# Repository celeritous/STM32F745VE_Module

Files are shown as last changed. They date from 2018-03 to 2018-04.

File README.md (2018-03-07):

# STM32F745VE_Module
This repository is for an STM32F745VE Cortex M7 32bit ARM processor module. The design supports most of the STM32F7xx processors in the QFP100 package. 

The design is in KiCad and is released under the CERN OHL Ver 1.2 It is on a 50mm x 50mm 4 layer PCB with two 38 Pin dual row 100mil headers for user power and IO. There is no on-board voltage regulation so the user must supply regulated 3.3V power to the board. 

Features include a USB FS and HS ports that can function as host or client as well as and optional uSD card slot and optional Ethernet RMII PHY chip and connector.  

Along with the hardware design, the repository also contains a sample STM32CubeMX pin assignemt project file and a sample Atollic TrueStudio project file generated by the STM32CubeMX project file.

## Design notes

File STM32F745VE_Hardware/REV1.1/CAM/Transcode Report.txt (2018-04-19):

   ---- Transcoding 'C:\Users\alitton\Dropbox\Github\STM32F745VE_Module\STM32F745VE_Hardware\REV1.1\CAM\STM32F745VE_REV1.1-B.Cu.gbl' ----   Wed Apr 11 17:01:41 2018

D11   --> D100
D12   --> D101
D13   --> D102
D14   --> D103
D15   --> D104
D16   --> D105
D17   --> D106
D18   --> D107
-----------------------------------------------------------------

   ---- Transcoding 'C:\Users\alitton\Dropbox\Github\STM32F745VE_Module\STM32F745VE_Hardware\REV1.1\CAM\STM32F745VE_REV1.1-B.Mask.gbs' ----   Wed Apr 11 17:01:41 2018

D11   --> D108
D12   --> D109
D13   --> D110
D14   --> D111
D15   --> D112
D16   --> D113
D17   --> D114
D18   --> D115
D19   --> D116
D20   --> D117
D21   --> D118
D22   --> D119
D23   --> D120
D24   --> D121
-----------------------------------------------------------------

   ---- Transcoding 'C:\Users\alitton\Dropbox\Github\STM32F745VE_Module\STM32F745VE_Hardware\REV1.1\CAM\STM32F745VE_REV1.1-B.SilkS.gbo' ----   Wed Apr 11 17:01:41 2018

D11   --> D122
D12   --> D123
D13   --> D124
D14   --> D125
D15   --> D126
D16   --> D127
-----------------------------------------------------------------

   ---- Transcoding 'C:\Users\alitton\Dropbox\Github\STM32F745VE_Module\STM32F745VE_Hardware\REV1.1\CAM\STM32F745VE_REV1.1-Edge.Cuts.gm1' ----   Wed Apr 11 17:01:41 2018

D11   --> D128
-----------------------------------------------------------------

   ---- Transcoding 'C:\Users\alitton\Dropbox\Github\STM32F745VE_Module\STM32F745VE_Hardware\REV1.1\CAM\STM32F745VE_REV1.1-F.Cu.gtl' ----   Wed Apr 11 17:01:41 2018

D11   --> D129
D12   --> D130
D13   --> D131
D14   --> D132
D15   --> D133
D16   --> D134
D17   --> D135
D18   --> D136
D19   --> D137
D20   --> D138
D21   --> D139
D22   --> D140
D23   --> D141
D24   --> D142
D25   --> D143
-----------------------------------------------------------------

   ---- Transcoding 'C:\Users\alitton\Dropbox\Github\STM32F745VE_Module\STM32F745VE_Hardware\REV1.1\CAM\STM32F745VE_REV1.1-F.Mask.gts' ----   Wed Apr 11 17:01:41 2018

D11   --> D144
D12   --> D145
D13   --> D146
D14   --> D147
D15   --> D148
D16   --> D149
D17   --> D150
D18   --> D151
D19   --> D152
D20   --> D153
D21   --> D154
D22   --> D155
D23   --> D156
D24   --> D157
D25   --> D158
-----------------------------------------------------------------

   ---- Transcoding 'C:\Users\alitton\Dropbox\Github\STM32F745VE_Module\STM32F745VE_Hardware\REV1.1\CAM\STM32F745VE_REV1.1-F.SilkS.gto' ----   Wed Apr 11 17:01:41 2018

D11   --> D159
D12   --> D160
D13   --> D161
D14   --> D162
D15   --> D163
D16   --> D164
-----------------------------------------------------------------

   ---- Transcoding 'C:\Users\alitton\Dropbox\Github\STM32F745VE_Module\STM32F745VE_Hardware\REV1.1\CAM\STM32F745VE_REV1.1-B.Cu.gbl' ----   Wed Apr 11 17:21:39 2018

D11   --> D100
D12   --> D101
D13   --> D102
D14   --> D103
D15   --> D104
D16   --> D105
D17   --> D106
D18   --> D107
-----------------------------------------------------------------

   ---- Transcoding 'C:\Users\alitton\Dropbox\Github\STM32F745VE_Module\STM32F745VE_Hardware\REV1.1\CAM\STM32F745VE_REV1.1-B.Mask.gbs' ----   Wed Apr 11 17:21:39 2018

D11   --> D108
D12   --> D109
D13   --> D110
D14   --> D111
D15   --> D112
D16   --> D113
D17   --> D114
D18   --> D115
D19   --> D116
D20   --> D117
D21   --> D118
D22   --> D119
D23   --> D120
D24   --> D121
-----------------------------------------------------------------

   ---- Transcoding 'C:\Users\alitton\Dropbox\Github\STM32F745VE_Module\STM32F745VE_Hardware\REV1.1\CAM\STM32F745VE_REV1.1-B.SilkS.gbo' ----   Wed Apr 11 17:21:39 2018

D11   --> D122
D12   --> D123
D13   --> D124
D14   --> D125
D15   --> D126
D16   --> D127
-----------------------------------------------------------------

   ---- Transcoding 'C:\Users\alitton\Dropbox\Github\STM32F745VE_Module\STM32F745VE_Hardware\REV1.1\CAM\STM32F745VE_REV1.1-Edge.Cuts.gm1' ----   Wed Apr 11 17:21:39 2018

D11   --> D128
-----------------------------------------------------------------

   ---- Transcoding 'C:\Users\alitton\Dropbox\Github\STM32F745VE_Module\STM32F745VE_Hardware\REV1.1\CAM\STM32F745VE_REV1.1-F.Cu.gtl' ----   Wed Apr 11 17:21:39 2018

D11   --> D129
D12   --> D130
D13   --> D131
D14   --> D132
D15   --> D133
D16   --> D134
D17   --> D135
D18   --> D136
D19   --> D137
D20   --> D138
D21   --> D139
D22   --> D140
D23   --> D141
D24   --> D142
D25   --> D143
-----------------------------------------------------------------

   ---- Transcoding 'C:\Users\alitton\Dropbox\Github\STM32F745VE_Module\STM32F745VE_Hardware\REV1.1\CAM\STM32F745VE_REV1.1-F.Mask.gts' ----   Wed Apr 11 17:21:39 2018

D11   --> D144
D12   --> D145
D13   --> D146
D14   --> D147
D15   --> D148
D16   --> D149
D17   --> D150
D18   --> D151
D19   --> D152
D20   --> D153
D21   --> D154
D22   --> D155
D23   --> D156
D24   --> D157
D25   --> D158
-----------------------------------------------------------------

   ---- Transcoding 'C:\Users\alitton\Dropbox\Github\STM32F745VE_Module\STM32F745VE_Hardware\REV1.1\CAM\STM32F745VE_REV1.1-F.SilkS.gto' ----   Wed Apr 11 17:21:39 2018

D11   --> D159
D12   --> D160
D13   --> D161
D14   --> D162
D15   --> D163
D16   --> D164
-----------------------------------------------------------------

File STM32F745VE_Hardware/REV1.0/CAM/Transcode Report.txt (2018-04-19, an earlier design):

   ---- Transcoding 'C:\Users\alitton\Dropbox\Github\STM32F745VE_Module\STM32F745VE_Hardware\REV1.0\CAM\STM32F745VE_Module-B.Cu.gbl' ----   Tue Apr 10 13:23:34 2018

D11   --> D100
D12   --> D101
D13   --> D102
D14   --> D103
D15   --> D104
D16   --> D105
D17   --> D106
D18   --> D107
-----------------------------------------------------------------

   ---- Transcoding 'C:\Users\alitton\Dropbox\Github\STM32F745VE_Module\STM32F745VE_Hardware\REV1.0\CAM\STM32F745VE_Module-F.Cu.gtl' ----   Tue Apr 10 13:23:34 2018

D11   --> D108
D12   --> D109
D13   --> D110
D14   --> D111
D15   --> D112
D16   --> D113
D17   --> D114
D18   --> D115
D19   --> D116
D20   --> D117
D21   --> D118
D22   --> D119
D23   --> D120
D24   --> D121
D25   --> D122
D26   --> D123
D27   --> D124
-----------------------------------------------------------------

   ---- Transcoding 'C:\Users\alitton\Dropbox\Github\STM32F745VE_Module\STM32F745VE_Hardware\REV1.0\CAM\STM32F745VE_Module-B.Mask.gbs' ----   Tue Apr 10 14:13:37 2018

D11   --> D125
D12   --> D126
D13   --> D127
D14   --> D128
D15   --> D129
D16   --> D130
D17   --> D131
D18   --> D132
D19   --> D133
D20   --> D134
D21   --> D135
D22   --> D136
D23   --> D137
-----------------------------------------------------------------

   ---- Transcoding 'C:\Users\alitton\Dropbox\Github\STM32F745VE_Module\STM32F745VE_Hardware\REV1.0\CAM\STM32F745VE_Module-B.SilkS.gbo' ----   Tue Apr 10 14:13:37 2018

D11   --> D138
D12   --> D139
D13   --> D140
D14   --> D141
D15   --> D142
D16   --> D143
-----------------------------------------------------------------

   ---- Transcoding 'C:\Users\alitton\Dropbox\Github\STM32F745VE_Module\STM32F745VE_Hardware\REV1.0\CAM\STM32F745VE_Module-Edge.Cuts.gm1' ----   Tue Apr 10 14:13:37 2018

D11   --> D144
-----------------------------------------------------------------

   ---- Transcoding 'C:\Users\alitton\Dropbox\Github\STM32F745VE_Module\STM32F745VE_Hardware\REV1.0\CAM\STM32F745VE_Module-F.Mask.gts' ----   Tue Apr 10 14:13:37 2018

D11   --> D145
D12   --> D146
D13   --> D147
D14   --> D148
D15   --> D149
D16   --> D150
D17   --> D151
D18   --> D152
D19   --> D153
D20   --> D154
D21   --> D155
D22   --> D156
D23   --> D157
D24   --> D158
D25   --> D159
-----------------------------------------------------------------

   ---- Transcoding 'C:\Users\alitton\Dropbox\Github\STM32F745VE_Module\STM32F745VE_Hardware\REV1.0\CAM\STM32F745VE_Module-F.SilkS.gto' ----   Tue Apr 10 14:13:37 2018

D11   --> D160
D12   --> D161
D13   --> D162
D14   --> D163
D15   --> D164
D16   --> D165
-----------------------------------------------------------------

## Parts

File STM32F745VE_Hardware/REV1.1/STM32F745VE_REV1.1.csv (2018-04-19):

Id | Designator | Package | Quantity | Designation
1 | C1,C2,C3,C4 | P0603 | 4 | 12pF
2 | D1,D2 | SOT23-6 | 2 | USBLC6-2
3 | J1 | CONNECTOR_ETHERNET_SI60062 | 1 | CONNECTOR_RJ45_SI-60062
4 | J3,J4 | CONN_USB_UX60-MB | 2 | USB_MINI_B_SMD
5 | U1 | QFP_100_14X14_0.5 | 1 | STM32F745VE
6 | U2 | QFN24_4X4mm_0.5mm_PWR | 1 | KSZ8081RNA
7 | U3 | SOT23-6 | 1 | 24AA02E64OT
8 | X1 | XTAL_1.8X4.9mm | 1 | ABS10-32.768kHz
9 | X2 | XTAL_3.2X2.5 | 1 | ABM8G-12.00MHz
10 | P2,P3 | Header_2x17_Shrouded_100mil | 2 | Header_2x17
11 | C5,C6,C8,C9,C11,C13,C14,C15,C16,C17 | P0603 | 10 | 0.10uF
12 | C7,C23,C24 | P0603 | 3 | 2.2uF
13 | C10,C12,C18,C19,C20,C21,C22 | P0603 | 7 | 10.0uF
14 | D3 | SOD123 | 1 | SMP3V3
15 | F1 | P1812 | 1 | FUSE_PTC_.75A_33V
16 | L1,L2 | P0603 | 2 | FERRITE_BEAD
17 | P4,P5 | Header_2x1_Shrouded_100mil | 2 | Header_2x1
18 | R1 | P0603 | 1 | 6.49kΩ
19 | R2,R3 | P0603 | 2 | 220.0Ω
20 | U4 | SOT23-6 | 1 | MCP1501-30
21 | P1 | Connector_1x4_100mil_TH | 1 | CONN_1x4
22 | J2 | CONN_SDMICRO_3M | 1 | SOCKET_MICRO_SD_SMT_3M
23 | C25 | P0603 | 1 | 0.010uF
24 | R4,R5,R6,R7,R8 | P0603 | 5 | 4.70kΩ
25 | SW1 | SWITCH_6MM_PB | 1 | PUSHBUTTON_SPST_6MM_SMD
26 | D4 | MINI_SMA | 1 | D_Small
29 | R9,R10 | P0603 | 2 | ZERO_Ω
30 | R11,R12 | P0603 | 2 | 1.50kΩ

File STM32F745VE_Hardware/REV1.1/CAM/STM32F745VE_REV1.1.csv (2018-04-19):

Id | Designator | Package | Quantity | Designation | Supplier and ref
1 | U1 | QFP_100_14X14_0.5 | 1 | STM32F745VE
2 | J2 | CONN_SDMICRO_3M | 1 | SOCKET_MICRO_SD_SMT_3M
3 | C1,C2,C3,C4 | P0603 | 4 | 12pF
4 | D1,D2 | SOT23-6 | 2 | USBLC6-2
5 | J1 | CONNECTOR_ETHERNET_SI60062 | 1 | CONNECTOR_RJ45_SI-60062
6 | J3,J4 | CONN_USB_UX60-MB | 2 | USB_MINI_B_SMD
7 | U2 | QFN24_4X4mm_0.5mm_PWR | 1 | KSZ8081RNA
8 | U3 | SOT23-6 | 1 | 24AA02E64OT
9 | X1 | XTAL_1.8X4.9mm | 1 | ABS10-32.768kHz
10 | X2 | XTAL_3.2X2.5 | 1 | ABM8G-12.00MHz
11 | P2,P3 | Header_2x17_Shrouded_100mil | 2 | Header_2x17
12 | C5,C6,C8,C9,C11,C13,C14,C15,C16,C17 | P0603 | 10 | 0.10uF
13 | C7,C23,C24 | P0603 | 3 | 2.2uF
14 | C10,C12,C18,C19,C20,C21,C22 | P0603 | 7 | 10.0uF
15 | D3 | SOD123 | 1 | SMP3V3
16 | F1 | P1812 | 1 | FUSE_PTC_.75A_33V
17 | L1,L2 | P0603 | 2 | FERRITE_BEAD
18 | P4,P5 | Header_2x1_Shrouded_100mil | 2 | Header_2x1
19 | R1 | P0603 | 1 | 6.49kΩ
20 | R2,R3 | P0603 | 2 | 220.0Ω
21 | U4 | SOT23-6 | 1 | MCP1501-30
22 | P1 | Connector_1x4_100mil_TH | 1 | CONN_1x4
23 | C25 | P0603 | 1 | 0.010uF
24 | R4,R5,R6,R7,R8,R14 | P0603 | 6 | 4.70kΩ
25 | SW1 | SWITCH_6MM_PB | 1 | PUSHBUTTON_SPST_6MM_SMD
26 | D4 | MINI_SMA | 1 | D_Small
27 | REF03,REF02 | FIDUCIAL_TOP | 2 | FIDUCIAL_TOP
28 | REF04,REF01 | FIDUCIAL_BOTTOM | 2 | FIDUCIAL_BOTTOM
29 | R9,R10,R13 | P0603 | 3 | ZERO_Ω
30 | R11,R12 | P0603 | 2 | 1.50kΩ

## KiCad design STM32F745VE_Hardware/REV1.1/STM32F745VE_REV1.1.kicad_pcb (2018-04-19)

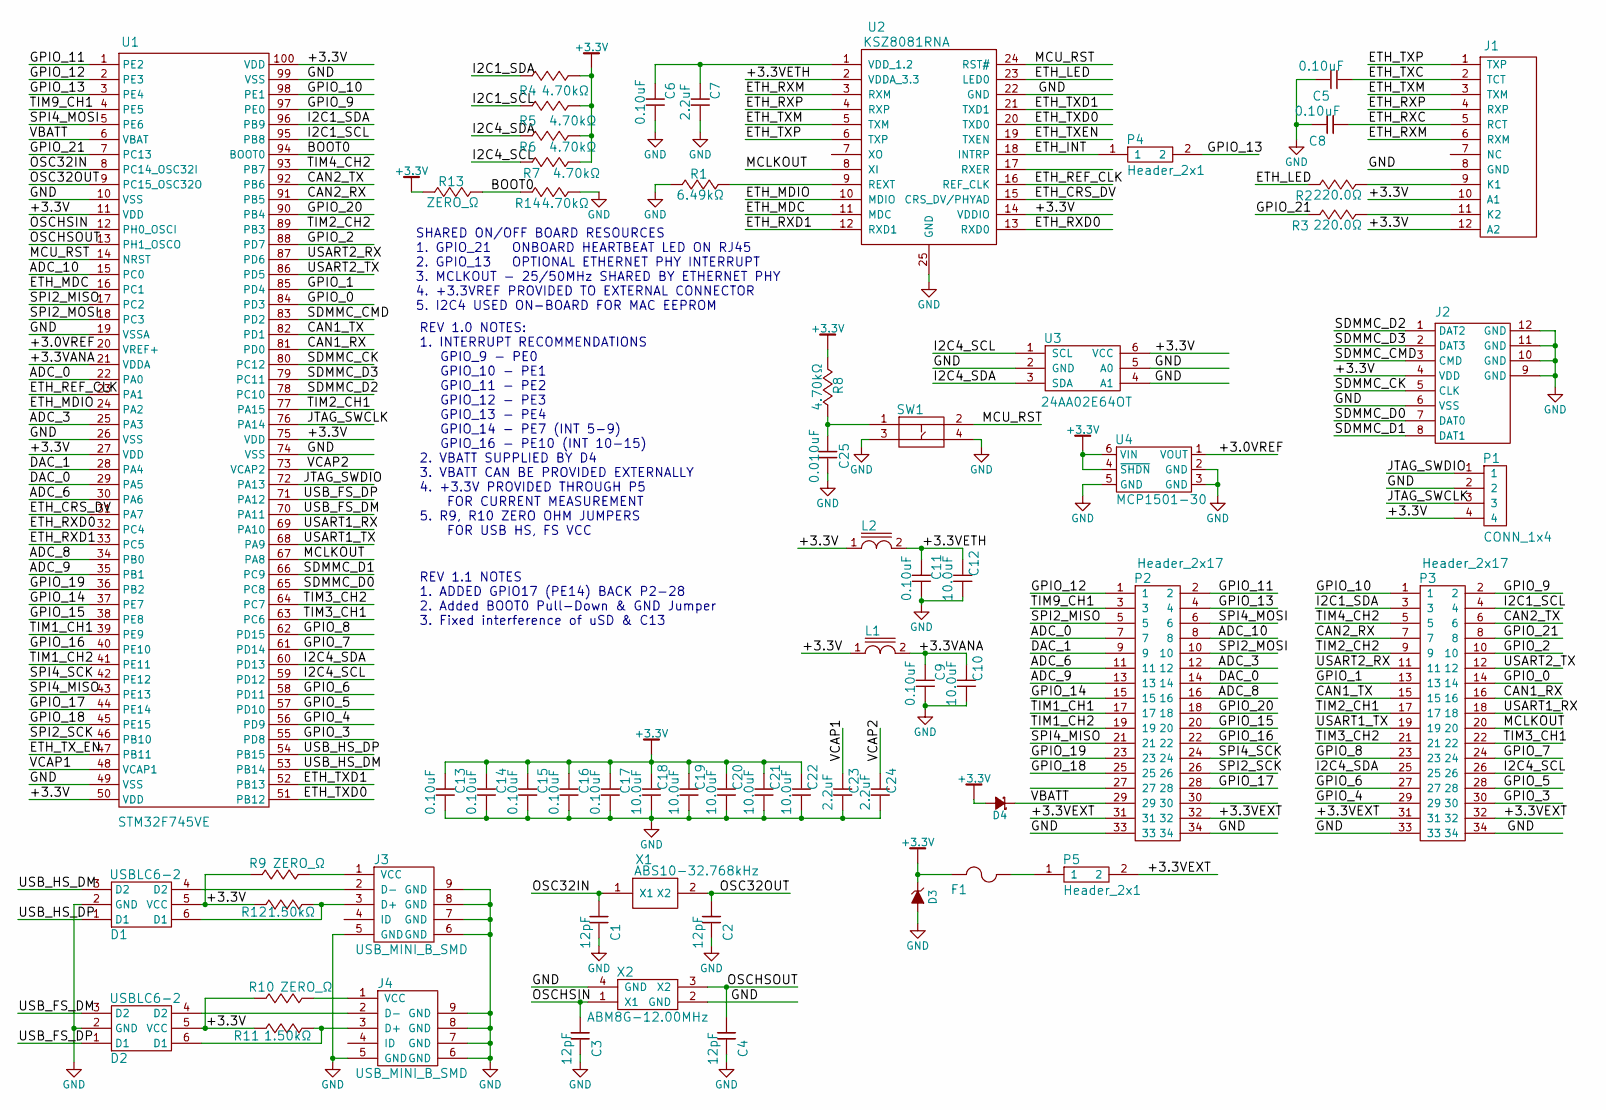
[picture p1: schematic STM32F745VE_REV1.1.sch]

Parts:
C1, C2, C3, C4: 12pF; P0603
C5, C6, C8, C9, C11, C13, C14, C15, C16, C17: 0.10uF; P0603
C7, C23, C24: 2.2uF; P0603
C10, C12, C18, C19, C20, C21, C22: 10.0uF; P0603
C25: 0.010uF; P0603
D1, D2: USBLC6-2; SOT23-6
D3: SMP3V3; DO220AA
D4: D_Small; MINI_SMA
F1: FUSE_PTC_.75A_33V; P1812
J1: CONNECTOR_RJ45_SI-60062; CONNECTOR_ETHERNET_SI60062
J2: SOCKET_MICRO_SD_SMT_3M; CONN_SDMICRO_3M
J3, J4: USB_MINI_B_SMD; CONN_USB_UX60-MB
L1, L2: FERRITE_BEAD; P0603
P1: CONN_1x4; Connector_1x4_100mil_TH
P2, P3: Header_2x17; Header_2x17_Shrouded_100mil
P4, P5: Header_2x1; Header_2x1_Shrouded_100mil
R1: 6.49kΩ; P0603
R2, R3: 220.0Ω; P0603
R4, R5, R6, R7, R8, R14: 4.70kΩ; P0603
R9, R10, R13: ZERO_Ω; P0603
R11, R12: 1.50kΩ; P0603
SW1: PUSHBUTTON_SPST_6MM_SMD; SWITCH_6MM_PB
U1: STM32F745VE; QFP_100_14X14_0.5
U2: KSZ8081RNA; QFN24_4X4mm_0.5mm_PWR
U3: 24AA02E64OT; SOT23-6
U4: MCP1501-30; SOT23-6
X1: ABS10-32.768kHz; XTAL_1.8X4.9mm
X2: ABM8G-12.00MHz; XTAL_3.2X2.5

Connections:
+3.3V: C13.1, C14.1, C15.1, C16.1, C17.1, C18.1, C19.1, C20.1, C21.1, C22.1, D1.5 (VCC), D2.5 (VCC), D3.K, D4.A, F1.1, J1.10 (A1), J1.12 (A2), J2.4 (VDD), L1.1, L2.1, P1.4, R4.2, R5.2, R6.2, R7.2, R8.1, R9.1, R10.1, R11.1, R12.2, R13.1, U1.11 (VDD), U1.27 (VDD), U1.50 (VDD), U1.75 (VDD), U1.100 (VDD), U2.14 (VDDIO), U3.6 (VCC), U4.4 (~SHDN), U4.6 (VIN)
/+3.0VREF: U1.20 (VREF+), U4.1 (VOUT)
/+3.3VANA: C9.1, C10.1, L1.2, U1.21 (VDDA)
/+3.3VETH: C11.1, C12.1, L2.2, U2.2 (VDDA_3.3)
/+3.3VEXT: P2.31, P2.32, P3.31, P3.32, P5.2
/ADC_0: P2.7, U1.22 (PA0)
/ADC_3: P2.12, U1.25 (PA3)
/ADC_6: P2.11, U1.30 (PA6)
/ADC_8: P2.16, U1.34 (PB0)
/ADC_9: P2.13, U1.35 (PB1)
/ADC_10: P2.8, U1.15 (PC0)
/BOOT0: R13.2, R14.1, U1.94 (BOOT0)
/CAN1_RX: P3.16, U1.81 (PD0)
/CAN1_TX: P3.15, U1.82 (PD1)
/CAN2_RX: P3.7, U1.91 (PB5)
/CAN2_TX: P3.6, U1.92 (PB6)
/DAC_0: P2.14, U1.29 (PA5)
/DAC_1: P2.9, U1.28 (PA4)
/ETH_CRS_DV: U1.31 (PA7), U2.15 (CRS_DV/PHYAD)
/ETH_INT: P4.1, U2.18 (INTRP)
/ETH_LED: R2.1, U2.23 (LED0)
/ETH_MDC: U1.16 (PC1), U2.11 (MDC)
/ETH_MDIO: U1.24 (PA2), U2.10 (MDIO)
/ETH_REF_CLK: U1.23 (PA1), U2.16 (REF_CLK)
/ETH_RXC: C8.1, J1.5 (RCT)
/ETH_RXD0: U1.32 (PC4), U2.13 (RXD0)
/ETH_RXD1: U1.33 (PC5), U2.12 (RXD1)
/ETH_RXM: J1.6 (RXM), U2.3 (RXM)
/ETH_RXP: J1.4 (RXP), U2.4 (RXP)
/ETH_TXC: C5.1, J1.2 (TCT)
/ETH_TXD0: U1.51 (PB12), U2.20 (TXD0)
/ETH_TXD1: U1.52 (PB13), U2.21 (TXD1)
/ETH_TXEN: U2.19 (TXEN)
/ETH_TXM: J1.3 (TXM), U2.5 (TXM)
/ETH_TXP: J1.1 (TXP), U2.6 (TXP)
/ETH_TX_EN: U1.47 (PB11)
/GPIO_0: P3.14, U1.84 (PD3)
/GPIO_1: P3.13, U1.85 (PD4)
/GPIO_2: P3.10, U1.88 (PD7)
/GPIO_3: P3.30, U1.55 (PD8)
/GPIO_4: P3.29, U1.56 (PD9)
/GPIO_5: P3.28, U1.57 (PD10)
/GPIO_6: P3.27, U1.58 (PD11)
/GPIO_7: P3.24, U1.61 (PD14)
/GPIO_8: P3.23, U1.62 (PD15)
/GPIO_9: P3.2, U1.97 (PE0)
/GPIO_10: P3.1, U1.98 (PE1)
/GPIO_11: P2.2, U1.1 (PE2)
/GPIO_12: P2.1, U1.2 (PE3)
/GPIO_13: P2.4, P4.2, U1.3 (PE4)
/GPIO_14: P2.15, U1.37 (PE7)
/GPIO_15: P2.20, U1.38 (PE8)
/GPIO_16: P2.22, U1.40 (PE10)
/GPIO_17: P2.28, U1.44 (PE14)
/GPIO_18: P2.25, U1.45 (PE15)
/GPIO_19: P2.23, U1.36 (PB2)
/GPIO_20: P2.18, U1.90 (PB4)
/GPIO_21: P3.8, R3.1, U1.7 (PC13)
/I2C1_SCL: P3.4, R5.1, U1.95 (PB8)
/I2C1_SDA: P3.3, R4.1, U1.96 (PB9)
/I2C4_SCL: P3.26, R7.1, U1.59 (PD12), U3.1 (SCL)
/I2C4_SDA: P3.25, R6.1, U1.60 (PD13), U3.3 (SDA)
/JTAG_SWCLK: P1.3, U1.76 (PA14)
/JTAG_SWDIO: P1.1, U1.72 (PA13)
/MCLKOUT: P3.20, U1.67 (PA8), U2.8 (XI)
/MCU_RST: SW1.2, U1.14 (NRST), U2.24 (RST#)
/OSC32IN: C1.1, U1.8 (PC14_OSC32I), X1.1 (X1)
/OSC32OUT: C2.1, U1.9 (PC15_OSC32O), X1.2 (X2)
/OSCHSIN: C3.1, U1.12 (PH0_OSCI), X2.1 (X1)
/OSCHSOUT: C4.1, U1.13 (PH1_OSCO), X2.3 (X2)
/SDMMC_CK: J2.5 (CLK), U1.80 (PC12)
/SDMMC_CMD: J2.3 (CMD), U1.83 (PD2)
/SDMMC_D0: J2.7 (DAT0), U1.65 (PC8)
/SDMMC_D1: J2.8 (DAT1), U1.66 (PC9)
/SDMMC_D2: J2.1 (DAT2), U1.78 (PC10)
/SDMMC_D3: J2.2 (DAT3), U1.79 (PC11)
/SPI2_MISO: P2.5, U1.17 (PC2)
/SPI2_MOSI: P2.10, U1.18 (PC3)
/SPI2_SCK: P2.26, U1.46 (PB10)
/SPI4_MISO: P2.21, U1.43 (PE13)
/SPI4_MOSI: P2.6, U1.5 (PE6)
/SPI4_SCK: P2.24, U1.42 (PE12)
/TIM1_CH1: P2.17, U1.39 (PE9)
/TIM1_CH2: P2.19, U1.41 (PE11)
/TIM2_CH1: P3.17, U1.77 (PA15)
/TIM2_CH2: P3.9, U1.89 (PB3)
/TIM3_CH1: P3.22, U1.63 (PC6)
/TIM3_CH2: P3.21, U1.64 (PC7)
/TIM4_CH2: P3.5, U1.93 (PB7)
/TIM9_CH1: P2.3, U1.4 (PE5)
/USART1_RX: P3.18, U1.69 (PA10)
/USART1_TX: P3.19, U1.68 (PA9)
/USART2_RX: P3.11, U1.87 (PD6)
/USART2_TX: P3.12, U1.86 (PD5)
/USB_FS_DM: D2.3 (D2), U1.70 (PA11)
/USB_FS_DP: D2.1 (D1), U1.71 (PA12)
/USB_HS_DM: D1.3 (D2), U1.53 (PB14)
/USB_HS_DP: D1.1 (D1), U1.54 (PB15)
/VBATT: D4.K, P2.29, U1.6 (VBAT)
/VCAP1: C23.1, U1.48 (VCAP1)
/VCAP2: C24.1, U1.73 (VCAP2)
GND: C1.2, C2.2, C3.2, C4.2, C5.2, C6.2, C7.2, C8.2, C9.2, C10.2, C11.2, C12.2, C13.2, C14.2, C15.2, C16.2, C17.2, C18.2, C19.2, C20.2, C21.2, C22.2, C23.2, C24.2, C25.2, D1.2 (GND), D2.2 (GND), D3.A, J1.8 (GND), J2.6 (VSS), J2.9 (GND), J2.10 (GND), J2.11 (GND), J2.12 (GND), J3.5 (GND), J3.6 (GND), J3.7 (GND), J3.8 (GND), J3.9 (GND), J4.5 (GND), J4.6 (GND), J4.7 (GND), J4.8 (GND), J4.9 (GND), P1.2, P2.33, P2.34, P3.33, P3.34, R1.1, R14.2, SW1.3, SW1.4, U1.10 (VSS), U1.19 (VSSA), U1.26 (VSS), U1.49 (VSS), U1.74 (VSS), U1.99 (VSS), U2.22 (GND), U2.25 (GND), U3.2 (GND), U3.4 (A1), U3.5 (A0), U4.2 (GND), U4.3 (GND), U4.5 (GND), X2.2 (GND), X2.4 (GND)
unnamed: C6.1, C7.1, U2.1 (VDD_1.2)
unnamed: C25.1, R8.2, SW1.1
unnamed: D1.4 (D2), J3.2 (D-)
unnamed: D1.6 (D1), J3.3 (D+), R12.1
unnamed: D2.4 (D2), J4.2 (D-)
unnamed: D2.6 (D1), J4.3 (D+), R11.2
unnamed: F1.2, P5.1
unnamed: J1.9 (K1), R2.2
unnamed: J1.11 (K2), R3.2
unnamed: J3.1 (VCC), R9.2
unnamed: J4.1 (VCC), R10.2
unnamed: R1.2, U2.9 (REXT)

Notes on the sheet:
SHARED ON/OFF BOARD RESOURCES 1. GPIO_21 ONBOARD HEARTBEAT LED ON RJ45 2. GPIO_13 OPTIONAL ETHERNET PHY INTERRUPT 3. MCLKOUT - 25/50MHz SHARED BY ETHERNET PHY 4. +3.3VREF PROVIDED TO EXTERNAL CONNECTOR 5. I2C4 USED ON-BOARD FOR MAC EEPROM
REV 1.0 NOTES: 1. INTERRUPT RECOMMENDATIONS GPIO_9 - PE0 GPIO_10 - PE1 GPIO_11 - PE2 GPIO_12 - PE3 GPIO_13 - PE4 GPIO_14 - PE7 (INT 5-9) GPIO_16 - PE10 (INT 10-15) 2. VBATT SUPPLIED BY D4 3. VBATT CAN BE PROVIDED EXTERNALLY 4. +3.3V PROVIDED THROUGH P5 FOR CURRENT MEASUREMENT 5. R9, R10 ZERO OHM JU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
REV 1.1 NOTES 1. ADDED GPIO17 (PE14) BACK P2-28 2. Added BOOT0 Pull-Down & GND Jumper 3. Fixed interference of uSD & C13

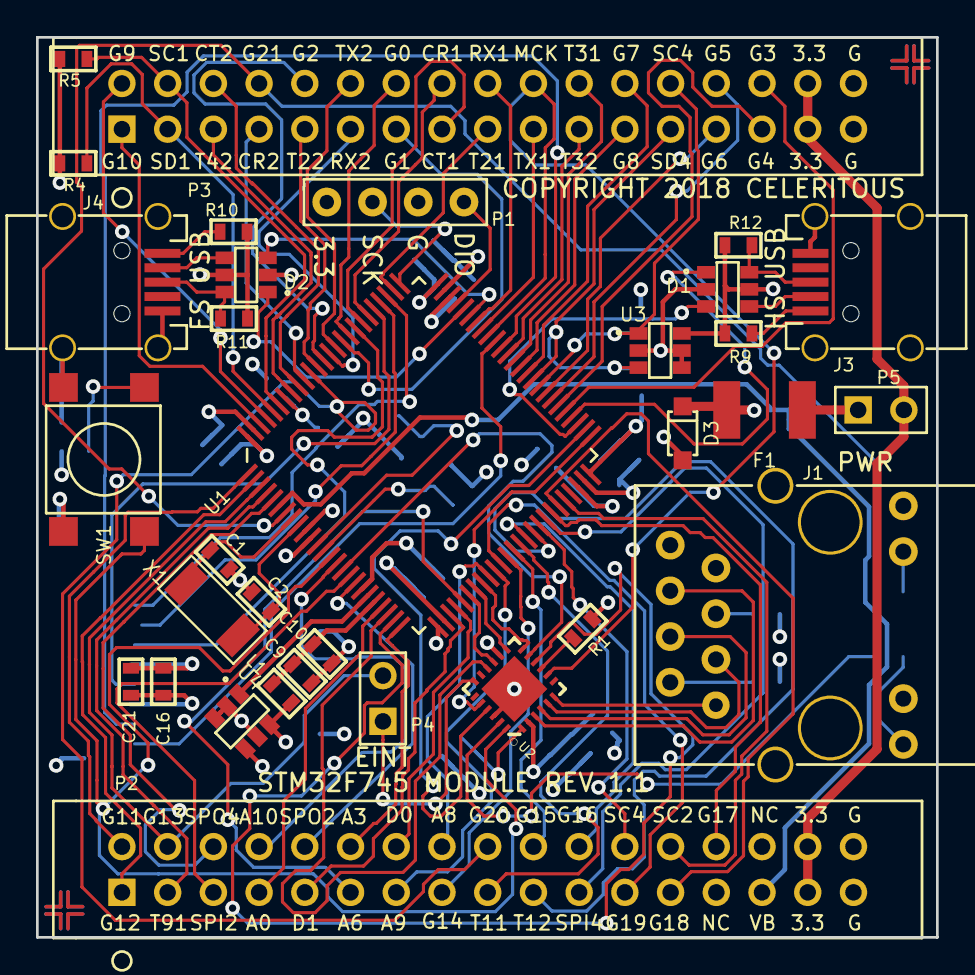
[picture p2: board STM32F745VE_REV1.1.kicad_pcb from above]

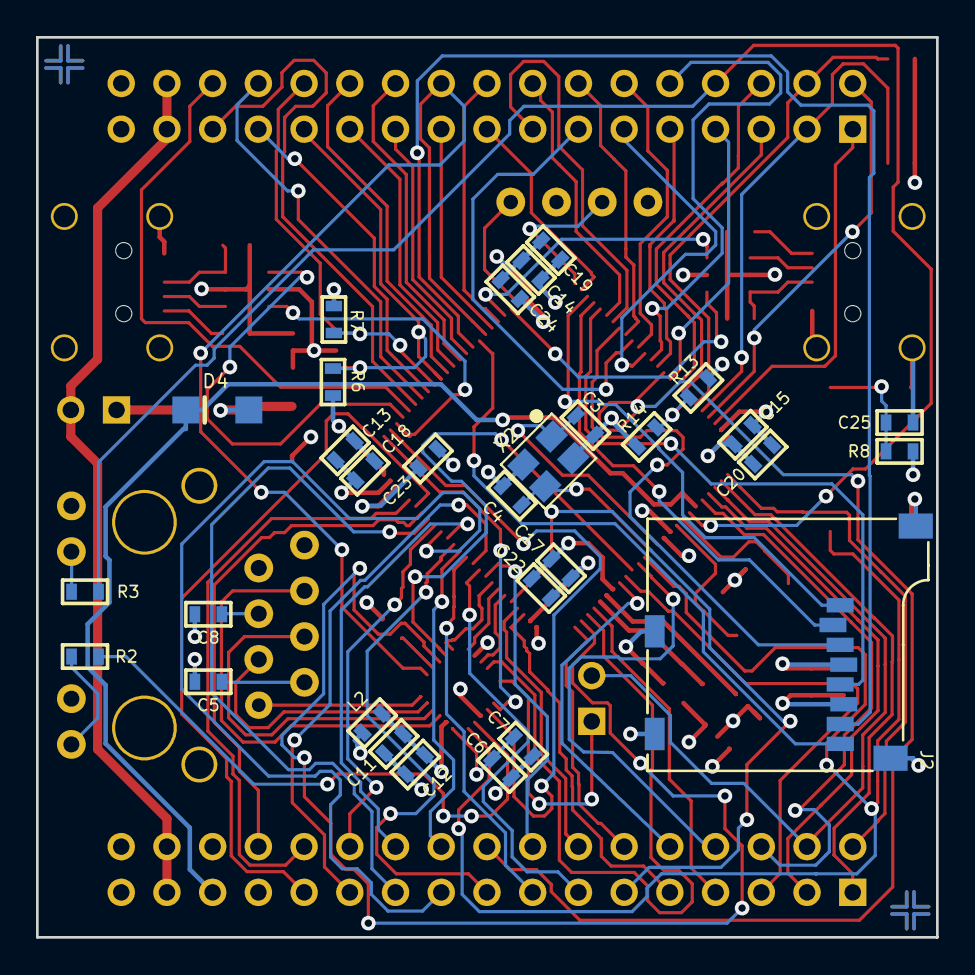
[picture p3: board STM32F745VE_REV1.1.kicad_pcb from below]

Board: 4 copper layers, 50.0 x 50.0 mm, 66 parts (30 on the bottom side), 112 nets.

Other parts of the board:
REF01, REF04: FIDUCIAL_BOTTOM
REF02, REF03: FIDUCIAL_TOP

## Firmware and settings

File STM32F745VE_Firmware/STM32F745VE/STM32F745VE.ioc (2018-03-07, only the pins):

Mcu.UserName=STM32F745VETx
PA0/WKUP.Signal=ADCx_IN0
PA1.Signal=ETH_REF_CLK
PA10.Signal=USART1_RX
PA11.Signal=USB_OTG_FS_DM
PA12.Signal=USB_OTG_FS_DP
PA13.Signal=SYS_JTMS-SWDIO
PA14.Signal=SYS_JTCK-SWCLK
PA15.Signal=S_TIM2_CH1_ETR
PA2.Signal=ETH_MDIO
PA3.Signal=ADCx_IN3
PA4.Signal=COMP_DAC1_group
PA5.Signal=COMP_DAC2_group
PA6.Signal=ADCx_IN6
PA7.Signal=ETH_CRS_DV
PA8.Signal=RCC_MCO_1
PA9.Signal=USART1_TX
PB0.Signal=ADCx_IN8
PB1.Signal=ADCx_IN9
PB10.Signal=SPI2_SCK
PB11.Signal=ETH_TX_EN
PB12.Signal=ETH_TXD0
PB13.Signal=ETH_TXD1
PB14.Signal=USB_OTG_HS_DM
PB15.Signal=USB_OTG_HS_DP
PB2.GPIO_Label=GPIO_20
PB2.Signal=GPIO_Input
PB3.Signal=S_TIM2_CH2
PB4.GPIO_Label=GPIO_21
PB4.Signal=GPIO_Input
PB5.Signal=CAN2_RX
PB6.Signal=CAN2_TX
PB7.Signal=S_TIM4_CH2
PB8.Signal=I2C1_SCL
PB9.Signal=I2C1_SDA
PC0.Signal=ADCx_IN10
PC1.Signal=ETH_MDC
PC10.Signal=SDMMC1_D2
PC11.Signal=SDMMC1_D3
PC12.Signal=SDMMC1_CK
PC13.GPIO_Label=GPIO_22
PC13.Signal=GPIO_Input
PC14/OSC32_IN.Signal=RCC_OSC32_IN
PC15/OSC32_OUT.Signal=RCC_OSC32_OUT
PC2.Signal=SPI2_MISO
PC3.Signal=SPI2_MOSI
PC4.Signal=ETH_RXD0
PC5.Signal=ETH_RXD1
PC6.Signal=S_TIM3_CH1
PC7.Signal=S_TIM3_CH2
PC8.Signal=SDMMC1_D0
PC9.Signal=SDMMC1_D1
PD0.Signal=CAN1_RX
PD1.Signal=CAN1_TX
PD10.GPIO_Label=GPIO_5
PD10.Signal=GPIO_Input
PD11.GPIO_Label=GPIO_6
PD11.Signal=GPIO_Input
PD12.Signal=I2C4_SCL
PD13.Signal=I2C4_SDA
PD14.GPIO_Label=GPIO_7
PD14.Signal=GPIO_Input
PD15.GPIO_Label=GPIO_8
PD15.Signal=GPIO_Input
PD2.Signal=SDMMC1_CMD
PD3.GPIO_Label=GPIO_0
PD3.Signal=GPIO_Input
PD4.GPIO_Label=GPIO_1
PD4.Signal=GPIO_Input
PD5.Signal=USART2_TX
PD6.Signal=USART2_RX
PD7.GPIO_Label=GPIO_2
PD7.Signal=GPIO_Input
PD8.GPIO_Label=GPIO_3
PD8.Signal=GPIO_Input
PD9.GPIO_Label=GPIO_4
PD9.Signal=GPIO_Input
PE0.GPIO_Label=GPIO_9
PE0.Signal=GPIO_Input
PE1.GPIO_Label=GPIO_10
PE1.Signal=GPIO_Input
PE10.GPIO_Label=GPIO_16
PE10.Signal=GPIO_Input
PE11.Signal=S_TIM1_CH2
PE12.GPIO_Label=GPIO_17
PE12.Signal=SPI4_SCK
PE13.Signal=SPI4_MISO
PE14.GPIO_Label=GPIO_18
PE14.Signal=GPIO_Input
PE15.GPIO_Label=GPIO_19
PE15.Signal=GPIO_Input
PE2.GPIO_Label=GPIO_11
PE2.Signal=GPIO_Input
PE3.GPIO_Label=GPIO_12
PE3.Signal=GPIO_Input
PE4.GPIO_Label=GPIO_13
PE4.Signal=GPIO_Input
PE5.Signal=S_TIM9_CH1
PE6.Signal=SPI4_MOSI
PE7.GPIO_Label=GPIO_14
PE7.Signal=GPIO_Input
PE8.GPIO_Label=GPIO_15
PE8.Signal=GPIO_Input
PE9.Signal=S_TIM1_CH1
PH0/OSC_IN.Signal=RCC_OSC_IN
PH1/OSC_OUT.Signal=RCC_OSC_OUT

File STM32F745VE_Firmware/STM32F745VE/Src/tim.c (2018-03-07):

/**
  ******************************************************************************
  * File Name          : TIM.c
  * Description        : This file provides code for the configuration
  *                      of the TIM instances.
  ******************************************************************************
  * This notice applies to any and all portions of this file
  * that are not between comment pairs USER CODE BEGIN and
  * USER CODE END. Other portions of this file, whether 
  * inserted by the user or by software development tools
  * are owned by their respective copyright owners.
  *
  * Copyright (c) 2018 STMicroelectronics International N.V. 
  * All rights reserved.
  *
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
  ******************************************************************************
  */

/* Includes ------------------------------------------------------------------*/
#include "tim.h"

#include "gpio.h"

TIM_HandleTypeDef htim1;
TIM_HandleTypeDef htim2;
TIM_HandleTypeDef htim3;
TIM_HandleTypeDef htim4;
TIM_HandleTypeDef htim5;
TIM_HandleTypeDef htim9;

/* TIM1 init function */
void MX_TIM1_Init(void)
{
  TIM_Encoder_InitTypeDef sConfig;
  TIM_MasterConfigTypeDef sMasterConfig;

  htim1.Instance = TIM1;
  htim1.Init.Prescaler = 0;
  htim1.Init.CounterMode = TIM_COUNTERMODE_UP;
  htim1.Init.Period = 0;
  htim1.Init.ClockDivision = TIM_CLOCKDIVISION_DIV1;
  htim1.Init.RepetitionCounter = 0;
  htim1.Init.AutoReloadPreload = TIM_AUTORELOAD_PRELOAD_DISABLE;
  sConfig.EncoderMode = TIM_ENCODERMODE_TI1;
  sConfig.IC1Polarity = TIM_ICPOLARITY_RISING;
  sConfig.IC1Selection = TIM_ICSELECTION_DIRECTTI;
  sConfig.IC1Prescaler = TIM_ICPSC_DIV1;
  sConfig.IC1Filter = 0;
  sConfig.IC2Polarity = TIM_ICPOLARITY_RISING;
  sConfig.IC2Selection = TIM_ICSELECTION_DIRECTTI;
  sConfig.IC2Prescaler = TIM_ICPSC_DIV1;
  sConfig.IC2Filter = 0;
  if (HAL_TIM_Encoder_Init(&htim1, &sConfig) != HAL_OK)
  {
    _Error_Handler(__FILE__, __LINE__);
  }

  sMasterConfig.MasterOutputTrigger = TIM_TRGO_RESET;
  sMasterConfig.MasterOutputTrigger2 = TIM_TRGO2_RESET;
  sMasterConfig.MasterSlaveMode = TIM_MASTERSLAVEMODE_DISABLE;
  if (HAL_TIMEx_MasterConfigSynchronization(&htim1, &sMasterConfig) != HAL_OK)
  {
    _Error_Handler(__FILE__, __LINE__);
  }

}
/* TIM2 init function */
void MX_TIM2_Init(void)
{
  TIM_Encoder_InitTypeDef sConfig;
  TIM_MasterConfigTypeDef sMasterConfig;

  htim2.Instance = TIM2;
  htim2.Init.Prescaler = 0;
  htim2.Init.CounterMode = TIM_COUNTERMODE_UP;
  htim2.Init.Period = 0;
  htim2.Init.ClockDivision = TIM_CLOCKDIVISION_DIV1;
  htim2.Init.AutoReloadPreload = TIM_AUTORELOAD_PRELOAD_DISABLE;
  sConfig.EncoderMode = TIM_ENCODERMODE_TI1;
  sConfig.IC1Polarity = TIM_ICPOLARITY_RISING;
  sConfig.IC1Selection = TIM_ICSELECTION_DIRECTTI;
  sConfig.IC1Prescaler = TIM_ICPSC_DIV1;
  sConfig.IC1Filter = 0;
  sConfig.IC2Polarity = TIM_ICPOLARITY_RISING;
  sConfig.IC2Selection = TIM_ICSELECTION_DIRECTTI;
  sConfig.IC2Prescaler = TIM_ICPSC_DIV1;
  sConfig.IC2Filter = 0;
  if (HAL_TIM_Encoder_Init(&htim2, &sConfig) != HAL_OK)
  {
    _Error_Handler(__FILE__, __LINE__);
  }

  sMasterConfig.MasterOutputTrigger = TIM_TRGO_RESET;
  sMasterConfig.MasterSlaveMode = TIM_MASTERSLAVEMODE_DISABLE;
  if (HAL_TIMEx_MasterConfigSynchronization(&htim2, &sMasterConfig) != HAL_OK)
  {
    _Error_Handler(__FILE__, __LINE__);
  }

}
/* TIM3 init function */
void MX_TIM3_Init(void)
{
  TIM_Encoder_InitTypeDef sConfig;
  TIM_MasterConfigTypeDef sMasterConfig;

  htim3.Instance = TIM3;
  htim3.Init.Prescaler = 0;
  htim3.Init.CounterMode = TIM_COUNTERMODE_UP;
  htim3.Init.Period = 0;
  htim3.Init.ClockDivision = TIM_CLOCKDIVISION_DIV1;
  htim3.Init.AutoReloadPreload = TIM_AUTORELOAD_PRELOAD_DISABLE;
  sConfig.EncoderMode = TIM_ENCODERMODE_TI1;
  sConfig.IC1Polarity = TIM_ICPOLARITY_RISING;
  sConfig.IC1Selection = TIM_ICSELECTION_DIRECTTI;
  sConfig.IC1Prescaler = TIM_ICPSC_DIV1;
  sConfig.IC1Filter = 0;
  sConfig.IC2Polarity = TIM_ICPOLARITY_RISING;
  sConfig.IC2Selection = TIM_ICSELECTION_DIRECTTI;
  sConfig.IC2Prescaler = TIM_ICPSC_DIV1;
  sConfig.IC2Filter = 0;
  if (HAL_TIM_Encoder_Init(&htim3, &sConfig) != HAL_OK)
  {
    _Error_Handler(__FILE__, __LINE__);
  }

  sMasterConfig.MasterOutputTrigger = TIM_TRGO_RESET;
  sMasterConfig.MasterSlaveMode = TIM_MASTERSLAVEMODE_DISABLE;
  if (HAL_TIMEx_MasterConfigSynchronization(&htim3, &sMasterConfig) != HAL_OK)
  {
    _Error_Handler(__FILE__, __LINE__);
  }

}
/* TIM4 init function */
void MX_TIM4_Init(void)
{
  TIM_ClockConfigTypeDef sClockSourceConfig;
  TIM_MasterConfigTypeDef sMasterConfig;
  TIM_OC_InitTypeDef sConfigOC;

  htim4.Instance = TIM4;
  htim4.Init.Prescaler = 0;
  htim4.Init.CounterMode = TIM_COUNTERMODE_UP;
  htim4.Init.Period = 0;
  htim4.Init.ClockDivision = TIM_CLOCKDIVISION_DIV1;
  htim4.Init.AutoReloadPreload = TIM_AUTORELOAD_PRELOAD_DISABLE;
  if (HAL_TIM_Base_Init(&htim4) != HAL_OK)
  {
    _Error_Handler(__FILE__, __LINE__);
  }

  sClockSourceConfig.ClockSource = TIM_CLOCKSOURCE_INTERNAL;
  if (HAL_TIM_ConfigClockSource(&htim4, &sClockSourceConfig) != HAL_OK)
  {
    _Error_Handler(__FILE__, __LINE__);
  }

  if (HAL_TIM_PWM_Init(&htim4) != HAL_OK)
  {
    _Error_Handler(__FILE__, __LINE__);
  }

  sMasterConfig.MasterOutputTrigger = TIM_TRGO_RESET;
  sMasterConfig.MasterSlaveMode = TIM_MASTERSLAVEMODE_DISABLE;
  if (HAL_TIMEx_MasterConfigSynchronization(&htim4, &sMasterConfig) != HAL_OK)
  {
    _Error_Handler(__FILE__, __LINE__);
  }

  sConfigOC.OCMode = TIM_OCMODE_PWM1;
  sConfigOC.Pulse = 0;
  sConfigOC.OCPolarity = TIM_OCPOLARITY_HIGH;
  sConfigOC.OCFastMode = TIM_OCFAST_DISABLE;
  if (HAL_TIM_PWM_ConfigChannel(&htim4, &sConfigOC, TIM_CHANNEL_2) != HAL_OK)
  {
    _Error_Handler(__FILE__, __LINE__);
  }

  HAL_TIM_MspPostInit(&htim4);

}
/* TIM5 init function */
void MX_TIM5_Init(void)
{
  TIM_ClockConfigTypeDef sClockSourceConfig;
  TIM_MasterConfigTypeDef sMasterConfig;

  htim5.Instance = TIM5;
  htim5.Init.Prescaler = 0;
  htim5.Init.CounterMode = TIM_COUNTERMODE_UP;
  htim5.Init.Period = 0;
  htim5.Init.ClockDivision = TIM_CLOCKDIVISION_DIV1;
  htim5.Init.AutoReloadPreload = TIM_AUTORELOAD_PRELOAD_DISABLE;
  if (HAL_TIM_Base_Init(&htim5) != HAL_OK)
  {
    _Error_Handler(__FILE__, __LINE__);
  }

  sClockSourceConfig.ClockSource = TIM_CLOCKSOURCE_INTERNAL;
  if (HAL_TIM_ConfigClockSource(&htim5, &sClockSourceConfig) != HAL_OK)
  {
    _Error_Handler(__FILE__, __LINE__);
  }

  sMasterConfig.MasterOutputTrigger = TIM_TRGO_RESET;
  sMasterConfig.MasterSlaveMode = TIM_MASTERSLAVEMODE_DISABLE;
  if (HAL_TIMEx_MasterConfigSynchronization(&htim5, &sMasterConfig) != HAL_OK)
  {
    _Error_Handler(__FILE__, __LINE__);
  }

}
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

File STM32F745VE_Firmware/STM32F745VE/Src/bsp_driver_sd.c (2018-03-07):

/**
 ******************************************************************************
  * @file    bsp_driver_sd.c for F7 (based on stm32756g_eval_sd.c)
  * @brief   This file includes a generic uSD card driver.
  ******************************************************************************
  * This notice applies to any and all portions of this file
  * that are not between comment pairs USER CODE BEGIN and
  * USER CODE END. Other portions of this file, whether 
  * inserted by the user or by software development tools
  * are owned by their respective copyright owners.
  *
  * Copyright (c) 2018 STMicroelectronics International N.V. 
  * All rights reserved.
  *
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
  ******************************************************************************
  */

#ifdef OLD_API
/* kept to avoid issue when migrating old projects. */
#else
/* USER CODE BEGIN FirstSection */
/* can be used to modify / undefine following code or add new definitions */
/* USER CODE END FirstSection */
/* Includes ------------------------------------------------------------------*/
#include "bsp_driver_sd.h"

/* Extern variables ---------------------------------------------------------*/ 
  
extern SD_HandleTypeDef hsd1;

/* USER CODE BEGIN BeforeInitSection */
/* can be used to modify / undefine following code or add code */
/* USER CODE END BeforeInitSection */
/**
  * @brief  Initializes the SD card device.
  * @retval SD status
  */
uint8_t BSP_SD_Init(void)
{
  uint8_t sd_state = MSD_OK;
  /* Check if the SD card is plugged in the slot */
  if (BSP_SD_IsDetected() != SD_PRESENT)
  {
    return MSD_ERROR_SD_NOT_PRESENT;
  }
  /* HAL SD initialization */
  sd_state = HAL_SD_Init(&hsd1);
  /* Configure SD Bus width (4 bits mode selected) */
  if (sd_state == MSD_OK)
  {
    /* Enable wide operation */
    if (HAL_SD_ConfigWideBusOperation(&hsd1, SDMMC_BUS_WIDE_4B) != HAL_OK)
    {
      sd_state = MSD_ERROR;
    }
  }

  return sd_state;
}
/* USER CODE BEGIN AfterInitSection */
/* can be used to modify previous code / undefine following code / add code */
/* USER CODE END AfterInitSection */

/**
  * @brief  Configures Interrupt mode for SD detection pin.
  * @retval Returns 0 in success otherwise 1. 
  */
uint8_t BSP_SD_ITConfig(void)
{  
  /* TBI: add user code here depending on the hardware configuration used */
  
  return (uint8_t)0;
}

/* USER CODE BEGIN BeforeReadBlocksSection */
/* can be used to modify previous code / undefine following code / add code */
/* USER CODE END BeforeReadBlocksSection */
/**
  * @brief  Reads block(s) from a specified address in an SD card, in polling mode.
  * @param  pData: Pointer to the buffer that will contain the data to transmit
  * @param  ReadAddr: Address from where data is to be read
  * @param  NumOfBlocks: Number of SD blocks to read
  * @param  Timeout: Timeout for read operation
  * @retval SD status
  */
uint8_t BSP_SD_ReadBlocks(uint32_t *pData, uint32_t ReadAddr, uint32_t NumOfBlocks, uint32_t Timeout)
{
  uint8_t sd_state = MSD_OK;

  if (HAL_SD_ReadBlocks(&hsd1, (uint8_t *)pData, ReadAddr, NumOfBlocks, Timeout) != HAL_OK)
  {
    sd_state = MSD_ERROR;
  }

  return sd_state;  
}

/* USER CODE BEGIN BeforeWriteBlocksSection */
/* can be used to modify previous code / undefine following code / add code */
/* USER CODE END BeforeWriteBlocksSection */
/**
  * @brief  Writes block(s) to a specified address in an SD card, in polling mode. 
  * @param  pData: Pointer to the buffer that will contain the data to transmit
  * @param  WriteAddr: Address from where data is to be written
  * @param  NumOfBlocks: Number of SD blocks to write
  * @param  Timeout: Timeout for write operation
  * @retval SD status
  */
uint8_t BSP_SD_WriteBlocks(uint32_t *pData, uint32_t WriteAddr, uint32_t NumOfBlocks, uint32_t Timeout)
{
  uint8_t sd_state = MSD_OK;

  if (HAL_SD_WriteBlocks(&hsd1, (uint8_t *)pData, WriteAddr, NumOfBlocks, Timeout) != HAL_OK) 
  {
    sd_state = MSD_ERROR;
  }

  return sd_state;  
}

/* USER CODE BEGIN BeforeReadDMABlocksSection */
/* can be used to modify previous code / undefine following code / add code */
/* USER CODE END BeforeReadDMABlocksSection */
/**
  * @brief  Reads block(s) from a specified address in an SD card, in DMA mode.
  * @param  pData: Pointer to the buffer that will contain the data to transmit
  * @param  ReadAddr: Address from where data is to be read
  * @param  NumOfBlocks: Number of SD blocks to read 
  * @retval SD status
  */
uint8_t BSP_SD_ReadBlocks_DMA(uint32_t *pData, uint32_t ReadAddr, uint32_t NumOfBlocks)
{
  uint8_t sd_state = MSD_OK;
  
  /* Read block(s) in DMA transfer mode */
  if (HAL_SD_ReadBlocks_DMA(&hsd1, (uint8_t *)pData, ReadAddr, NumOfBlocks) != HAL_OK)
  {
    sd_state = MSD_ERROR;
  }
  
  return sd_state; 
}

/* USER CODE BEGIN BeforeWriteDMABlocksSection */
/* can be used to modify previous code / undefine following code / add code */
/* USER CODE END BeforeWriteDMABlocksSection */
/**
  * @brief  Writes block(s) to a specified address in an SD card, in DMA mode.
  * @param  pData: Pointer to the buffer that will contain the data to transmit
  * @param  WriteAddr: Address from where data is to be written
  * @param  NumOfBlocks: Number of SD blocks to write 
  * @retval SD status
  */
uint8_t BSP_SD_WriteBlocks_DMA(uint32_t *pData, uint32_t WriteAddr, uint32_t NumOfBlocks)
{
  uint8_t sd_state = MSD_OK;
  
  /* Write block(s) in DMA transfer mode */
  if (HAL_SD_WriteBlocks_DMA(&hsd1, (uint8_t *)pData, WriteAddr, NumOfBlocks) != HAL_OK)
  {
    sd_state = MSD_ERROR;
  }
  
  return sd_state; 
}

/* USER CODE BEGIN BeforeEraseSection */
/* can be used to modify previous code / undefine following code / add code */
/* USER CODE END BeforeEraseSection */
/**
  * @brief  Erases the specified memory area of the given SD card. 
  * @param  StartAddr: Start byte address
  * @param  EndAddr: End byte address
  * @retval SD status
  */
uint8_t BSP_SD_Erase(uint32_t StartAddr, uint32_t EndAddr)
{
  uint8_t sd_state = MSD_OK;

  if (HAL_SD_Erase(&hsd1, StartAddr, EndAddr) != HAL_OK)  
  {
    sd_state = MSD_ERROR;
  }

  return sd_state; 
}

/* USER CODE BEGIN BeforeGetCardStateSection */
/* can be used to modify previous code / undefine following code / add code */
/* USER CODE END BeforeGetCardStateSection */
/**
  * @brief  Gets the current SD card data status.
  * @param  None
  * @retval Data transfer state.
  *          This value can be one of the following values:
  *            @arg  SD_TRANSFER_OK: No data transfer is acting
  *            @arg  SD_TRANSFER_BUSY: Data transfer is acting
  */
uint8_t BSP_SD_GetCardState(void)
{
  return ((HAL_SD_GetCardState(&hsd1) == HAL_SD_CARD_TRANSFER ) ? SD_TRANSFER_OK : SD_TRANSFER_BUSY);
}
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

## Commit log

2018-03-07 STM32F745VE KiCAD Initial coomit
    STM32F745VE KiCAD Initial coomit
    [STM32F745VE_Module.dsn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]
2018-03-07 Commit with TrueStudio & Cube project
    [STM32F745VE_Module.dsn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]
2018-04-19 Rev 1.1 update
    [STM32F745VE_Module-B.Cu.gbl, STM32F745VE_Module-B.Mask.gbs, STM32F745VE_Module-B.SilkS.gbo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]

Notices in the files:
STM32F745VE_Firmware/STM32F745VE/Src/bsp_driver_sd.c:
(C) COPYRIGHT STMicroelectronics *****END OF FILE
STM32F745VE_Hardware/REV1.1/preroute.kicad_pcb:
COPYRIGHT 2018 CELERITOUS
